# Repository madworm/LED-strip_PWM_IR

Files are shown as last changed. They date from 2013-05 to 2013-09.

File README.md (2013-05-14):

LED-strip_PWM_IR
================

LAYOUT FILES: Small high-current PWM controller with IR receiver (ATtiny85 based). 

---

Before having PC-boards made, please make sure you know about your manufacturer's peculiarities!
Especially drill-sizes and their tolerances may vary too much and give you trouble.

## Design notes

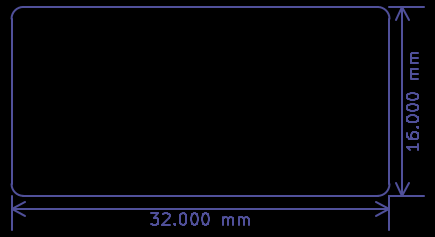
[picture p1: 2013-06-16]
gerber_files/PNGs/LED-strip_PWM_IR-Cmts_User.gbr.png

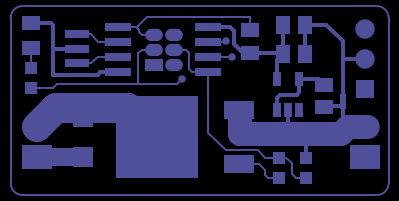
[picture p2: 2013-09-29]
gerber_files/PNGs/LED-strip_PWM_IR-F_Cu.gtl.png

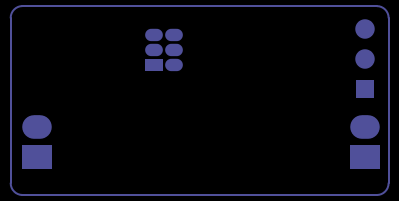
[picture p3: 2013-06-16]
gerber_files/PNGs/LED-strip_PWM_IR-B_Mask.gbs.png

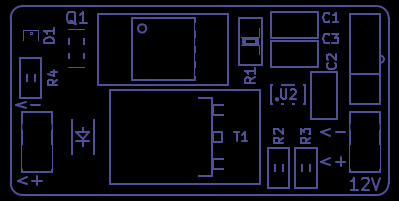
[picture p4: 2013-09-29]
gerber_files/PNGs/LED-strip_PWM_IR-F_SilkS.gto.png

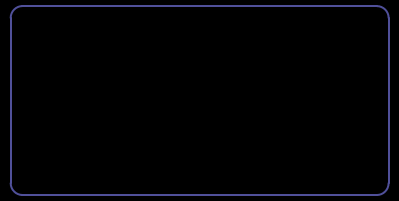
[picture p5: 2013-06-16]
gerber_files/PNGs/LED-strip_PWM_IR-Edge_Cuts.gbr.png

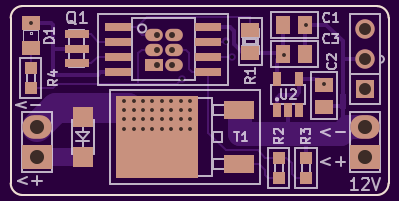
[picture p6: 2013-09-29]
gerber_files/PNGs/LED-strip_PWM_IR__front_purple.png

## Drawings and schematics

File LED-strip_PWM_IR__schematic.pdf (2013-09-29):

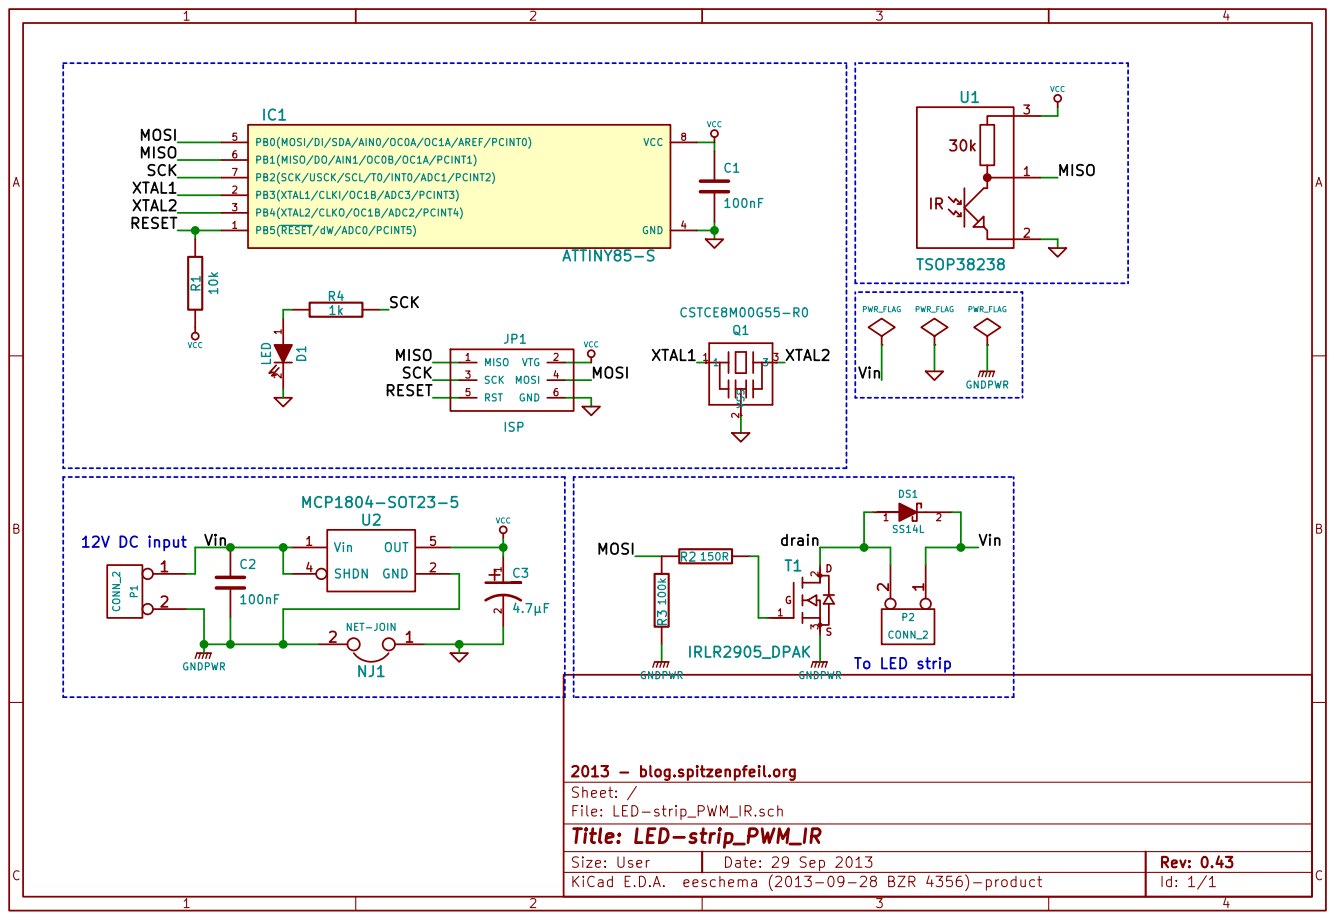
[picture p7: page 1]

File: LED-strip_PWM_IR.sch Sheet: / 2013 - blog.spitzenpfeil.org

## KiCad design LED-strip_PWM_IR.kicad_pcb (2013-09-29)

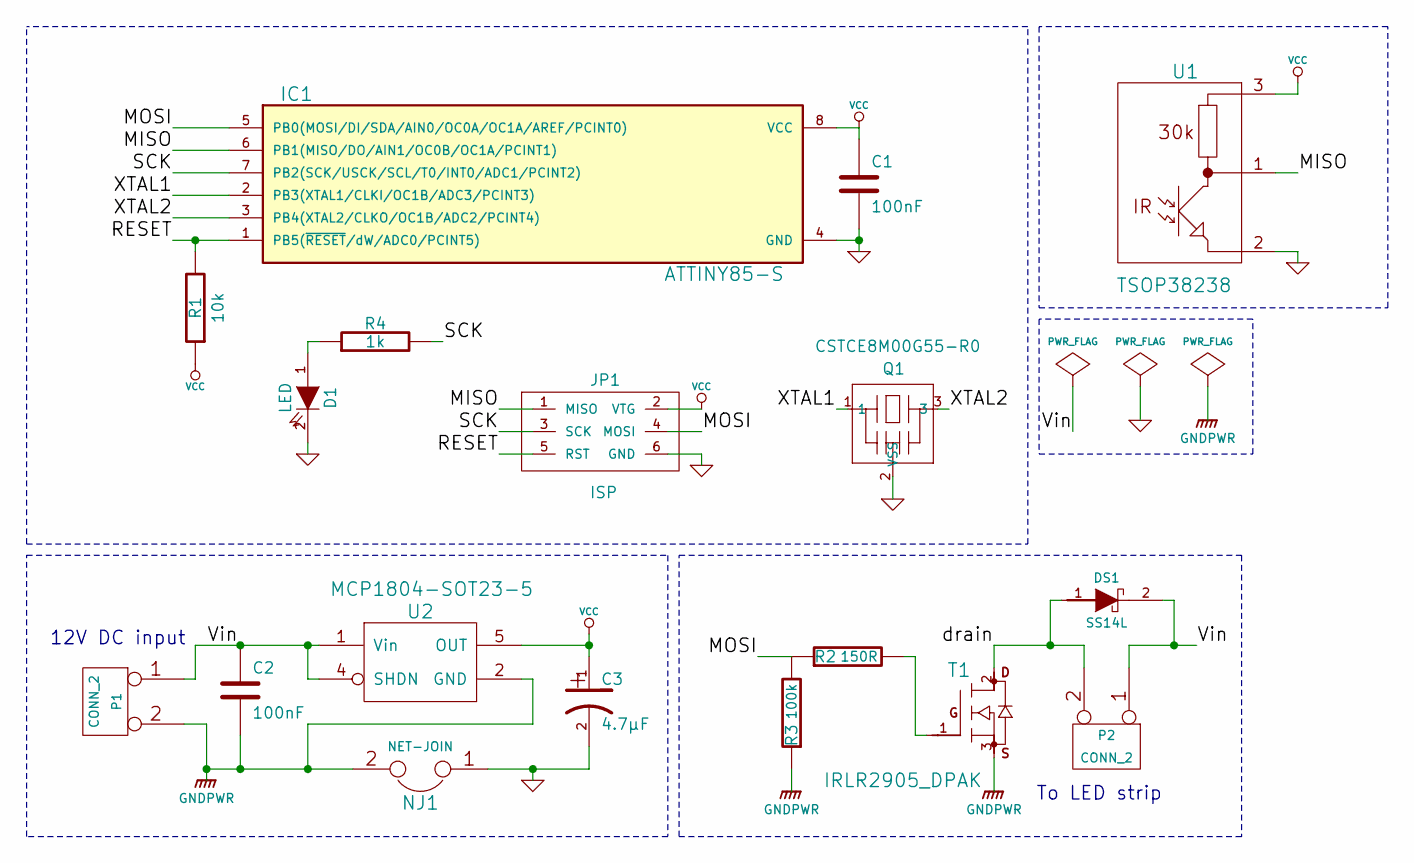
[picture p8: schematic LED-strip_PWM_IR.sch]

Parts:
C1, C2: 100nF
C3: 4.7µF
D1: LED
DS1: SS14L
IC1: ATTINY85-S
JP1: ISP
NJ1: NET-JOIN
P1, P2: CONN_2
Q1: CSTCE8M00G55-R0
R1: 10k
R2: 150R
R3: 100k
R4: 1k
T1: IRLR2905_DPAK
U1: TSOP38238
U2: MCP1804-SOT23-5

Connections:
/MISO: IC1.6 (PB1(MISO/DO/AIN1/OC0B/OC1A/PCINT1)), JP1.1 (MISO), U1.1
/MOSI: IC1.5 (PB0(MOSI/DI/SDA/AIN0/OC0A/OC1A/AREF/PCI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), JP1.4 (MOSI), R2.1, R3.2
/RESET: IC1.1 (PB5(~RESET~/dW/ADC0/PCINT5)), JP1.5 (RST), R1.2
/SCK: IC1.7 (PB2(SCK/USCK/SCL/T0/INT0/ADC1/PCINT2)), JP1.3 (SCK), R4.2
/Vin: C2.1, DS1.2 (C), P1.1, P2.1, U2.1 (Vin), U2.4 (SHDN)
/XTAL1: IC1.2 (PB3(XTAL1/CLKI/OC1B/ADC3/PCINT3)), Q1.1
/XTAL2: IC1.3 (PB4(XTAL2/CLKO/OC1B/ADC2/PCINT4)), Q1.3
/drain: DS1.1 (A), P2.2 (PM), T1.2 (D)
GND: C1.2, C3.2, D1.2 (K), IC1.4 (GND), JP1.6 (GND), NJ1.1, Q1.2 (VSS), U1.2
GNDPWR: C2.2, NJ1.2, P1.2 (PM), R3.1, T1.3 (S), U2.2 (GND)
Net-<D1-Pad1>: D1.1 (A), R4.1
Net-<R2-Pad2>: R2.2, T1.1 (G)
VCC: C1.1, C3.1, IC1.8 (VCC), JP1.2 (VTG), R1.1, U1.3, U2.5 (OUT)

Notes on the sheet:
To LED strip
12V DC input

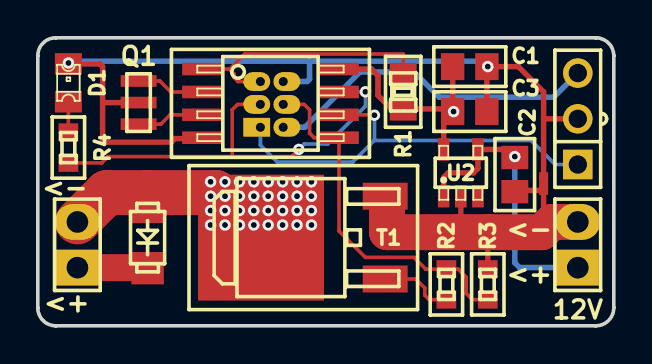
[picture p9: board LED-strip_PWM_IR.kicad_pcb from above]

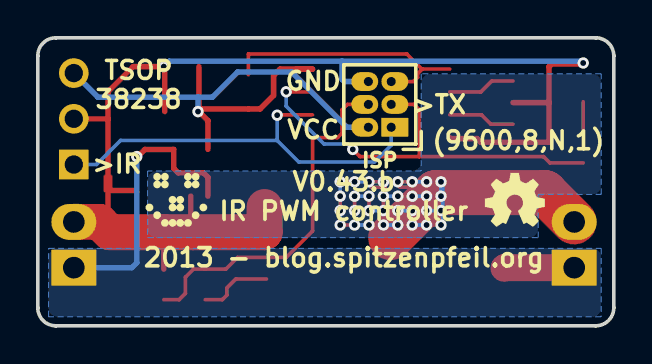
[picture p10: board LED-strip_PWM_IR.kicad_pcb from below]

Board: 2 copper layers, 32.0 x 16.0 mm, 20 parts (3 on the bottom side), 13 nets.

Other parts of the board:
G1: LOGO
G2: LOGO

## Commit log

2012-11-25 Logic GND was sharing a high-current path. Fixed.
    [LED-strip_PWM_IR.brd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]
2012-11-25 Flipped IN/OUT connectors (less copper) + bigger holes.
    [LED-strip_PWM_IR.brd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]
2012-11-25 Replaced: TO-252 footprint with a custom one (larger pads) + tweaks.
    [LED-strip_PWM_IR.brd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]
2012-11-25 FET resistor --> 0603 + new place.
    [LED-strip_PWM_IR.brd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]
2012-11-26 Changed IRLR2905 gate resistor to 150R.
    [LED-strip_PWM_IR.brd, LED-strip_PWM_IR.sch]
2012-11-27 Added bottom copper zone as heatsink for the MOSFET.
    [LED-strip_PWM_IR.brd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]
2012-11-27 Fixed murata resonator (CSTCC) footprint.
    [LED-strip_PWM_IR.brd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]
2012-11-27 Added a 20k gate pull-down.
    [LED-strip_PWM_IR.brd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]
2012-11-28 Shifted vias to stay clear of the back heatsink copper zone.
    [LED-strip_PWM_IR.brd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]
2012-11-28 Moved board to align with a 1mm grid.
    [LED-strip_PWM_IR.brd]
2013-01-08 Fixed the ATtiny85 footprint issue.
    [LED-strip_PWM_IR.brd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]
2013-01-08 Silkscreen tweaks.
    [LED-strip_PWM_IR.brd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]
2013-01-09 Replaced 78L05 with MCP1804-SOT23 (low drop). Board-shrink.
    [LED-strip_PWM_IR.brd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]
2013-01-09 B-Silkscreen fixed.
    [LED-strip_PWM_IR.brd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]
2013-01-09 Added a LED as IR reception indicator (optional).
    [LED-strip_PWM_IR.brd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]
2013-01-09 Increased the drill-size for the TSOP38328 to 40mil.
    [LED-strip_PWM_IR.brd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]
2013-01-09 Adapted to the changed MCP1804-SOT23-5 schematic symbol.
    No changes to the board layout itself, only behind the scenes stuff.
    [LED-strip_PWM_IR.brd, LED-strip_PWM_IR.sch]
2013-01-12 Shoved some parts around, maybe it looks nicer now. Maybe not...
    [LED-strip_PWM_IR.brd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]
2013-01-13 Power traces: 8mil --> 12mil.
    [LED-strip_PWM_IR.brd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]
2013-01-15 Tweaked b-silkscreen.
    [LED-strip_PWM_IR.brd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]
2013-01-16 Silkscreen tweaks + removed all (via-in-pad)s.
    [LED-strip_PWM_IR.brd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]
2013-01-20 Added a comments layer with board dimensions.
    [LED-strip_PWM_IR.brd]
2013-01-26 Replaced the jumper with a real net-tie footprint.
    [LED-strip_PWM_IR-B_Mask.gbs, LED-strip_PWM_IR-B_SilkS.gbo, LED-strip_PWM_IR-Back.gbl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]
2013-01-27 Switched to REV. 202 of atmel.lib
    [LED-strip_PWM_IR.brd, LED-strip_PWM_IR.sch]
2013-01-27 Wrong LED footprint. Was 0603, should've been 0805. GAH!
    [LED-strip_PWM_IR-B_Mask.gbs, LED-strip_PWM_IR-B_SilkS.gbo, LED-strip_PWM_IR-Back.gbl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]
2013-02-09 Changed MCP1804 footprint: SOT23-5 --> SOT23-5L
    [LED-strip_PWM_IR-B_Mask.gbs, LED-strip_PWM_IR-B_SilkS.gbo, LED-strip_PWM_IR-Back.gbl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]
2013-02-09 Increased pad-size of headers for wider annular ring + small tweaks.
    [LED-strip_PWM_IR-B_Mask.gbs, LED-strip_PWM_IR-B_SilkS.gbo, LED-strip_PWM_IR-Back.gbl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]
2013-02-12 Moved the LED to the left side of the board, away from the IR receiver.
    [LED-strip_PWM_IR-B_Mask.gbs, LED-strip_PWM_IR-B_SilkS.gbo, LED-strip_PWM_IR-Back.gbl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]
2013-02-12 Changed the resonator type: CSTCC --> CSTCE. About 1/2 the size.
    [LED-strip_PWM_IR-B_Mask.gbs, LED-strip_PWM_IR-B_SilkS.gbo, LED-strip_PWM_IR-Back.gbl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]
2013-02-13 Moved footprints --> board shrunk by 1mm in height.
    [LED-strip_PWM_IR-B_Mask.gbs, LED-strip_PWM_IR-B_SilkS.gbo, LED-strip_PWM_IR-Back.gbl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]
2013-02-13 Larger pads for the new CSTCE oscillator. Hand soldering...
    [LED-strip_PWM_IR-B_Mask.gbs, LED-strip_PWM_IR-B_SilkS.gbo, LED-strip_PWM_IR-Back.gbl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]
2013-02-15 Added some artwork to the back side ;-)
    [LED-strip_PWM_IR.brd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]
2013-05-17 Added a protection Schottky-Diode for the MOSFET. Now V0.3
    [LED-strip_PWM_IR-B_Cu.gbl, LED-strip_PWM_IR-B_Mask.gbs, LED-strip_PWM_IR-B_SilkS.gbo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]
2013-05-19 Re-spun the board again: square shape --> oblong shape.
    [LED-strip_PWM_IR.brd, LED-strip_PWM_IR.sch]
2013-05-19 Recrated gerber-files + PNGs.
    [LED-strip_PWM_IR-B_Cu.gbl, LED-strip_PWM_IR-B_Mask.gbs, LED-strip_PWM_IR-B_SilkS.gbo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]
2013-05-19 Grmbl! Never trust footprints from 'some lib'...
    [LED-strip_PWM_IR.brd, LED-strip_PWM_IR.kicad_pcb, LED-strip_PWM_IR.sch]
2013-05-19 Recreated gerber-files.
    [LED-strip_PWM_IR-B_Cu.gbl, LED-strip_PWM_IR-B_Mask.gbs, LED-strip_PWM_IR-B_SilkS.gbo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]
2013-05-19 Fixed a brain-fart... Why use a direct trace, if you can use lots of vias?
    [LED-strip_PWM_IR-B_Cu.gbl, LED-strip_PWM_IR-B_Mask.gbs, LED-strip_PWM_IR-B_SilkS.gbo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]
2013-05-24 Added heat-sink copper-pour with lots of vias again. Board-Rev. 0.42
    [LED-strip_PWM_IR-B_Cu.gbl, LED-strip_PWM_IR-B_Mask.gbs, LED-strip_PWM_IR-B_SilkS.gbo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]
2013-06-16 Switched Schottky diode to SS14L + rounded corners.
    [LED-strip_PWM_IR-B_Cu.gbl, LED-strip_PWM_IR-B_Mask.gbs, LED-strip_PWM_IR-B_SilkS.gbo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]
2013-09-29 Fixed resonator footprint (library part was off).
    [LED-strip_PWM_IR-B_Cu.gbl, LED-strip_PWM_IR-B_Mask.gbs, LED-strip_PWM_IR-B_SilkS.gbo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]
